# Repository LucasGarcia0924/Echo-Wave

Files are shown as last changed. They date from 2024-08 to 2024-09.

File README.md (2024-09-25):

# Echo-Wave
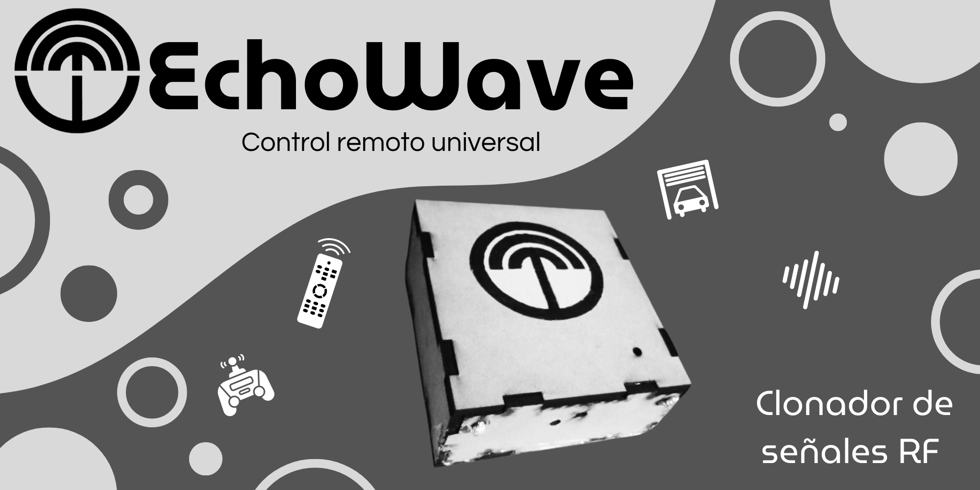
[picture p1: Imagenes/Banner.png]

Banner 

## Descripción 
Dispositivo capaz de clonar señales RF de 433mhz, siendo controlado desde una App Movil

Proyecto final asignatura de Taller de Electrónica 2024-1

Universidad Nacional de Colombia
### Integrantes
* Lucas Garcia Alvarez
* Julian Gustin Moreno
* Kevin Castellanos Peña
* Santiago Navarro

## Introducción
El proyecto EchoWave se creó con la idea de facilitar la clonación de señales RF de controles remotos de distintos tipos, utilizando materiales de bajo costo para crear un dispositivo capaz de replicar y usar dichas señales. 

## La problemática
En la actualidad, el uso de controles remotos para dispositivos que emiten señales RF, como televisores, luces y otros equipos, se ha vuelto parte de las actividades cotidianas. Sin embargo, los usuarios enfrentan varios inconvenientes:

- Limitaciones de compatibilidad: Muchas veces los usuarios necesitan múltiples controles remotos, cada uno con una función específica, lo que resulta incómodo y poco eficiente.
- Falta de flexibilidad: Las tecnologías existentes no permiten la clonación o replicación de señales de RF de manera sencilla, lo que genera frustración entre los usuarios que requieren soluciones rápidas y accesibles.
- Riesgos de seguridad: Clonar señales RF sin los adecuados controles de seguridad puede conllevar riesgos, lo que hace que los usuarios se sientan inseguros al intentar utilizar tecnologías más flexibles.
Estas problemáticas crean la necesidad de desarrollar soluciones más accesibles y económicas que permitan clonar y utilizar señales RF de manera segura y eficiente, facilitando así las acciones cotidianas de los usuarios.

El proyecto EchoWave busca solucionar esta problemática mediante la creación de un dispositivo de bajo costo, flexible y eficiente, que permita la clonación y uso de señales de RF de manera segura, mejorando la experiencia del usuario y reduciendo la cantidad de controles remotos necesarios para interactuar con múltiples dispositivos.
## La solución planteada (los módulos usados)
La solución se diseña a partir de tecnologías simples, de fácil acceso y fabricación, enfocados en parte a que sea algo accesible para todo el mundo, por lo que a partir de esto y demás requisitos descritos a continuacion, se eligen los siguientes componentes:
- Chip ESP32
- Batería Recargable IN18650
- Modulo MHCD 42
- Transceptor HC-12
- Servomotor SG90
- Zumbador
- Case en Impresion 3D y Corte Laser
## El funcionamiento del proyecto desde el punto de vista del usuario

El EchoWave funciona como un control remoto universal, que mediante una aplicación, clona señales RF, como las de un control de televisor, controles para puertas de garaje o portones, y otros dispositivos similares  
Su uso consta tan solo de descargar la aplicación, clonar señales, cargar el dispositivo mediante el cable incluido y bloquear las señales con el pulsador en la parte superior del case.

## Recomendaciones y conclusiones
### Conclusiones:
En este proyecto se logró avanzar en le creación de una herramienta capaz de simplificar las tarjetas de acceso y controles a distancia de forma compacta, sin embargo, se enfocó el proyecto a las señales de radiofrecuencia, donde por medio de un transceptor recibe estas señales. Dentro del proyecto se utilizaron componentes con presupuesto reducido, confirmando que en el mercado se consiguen dispositivos de bajo precio y con las características que permiten manejar las diferentes señales y comunicaciones que se implementan aquí. Se plantea en un futuro implementarle la opción de usarse a bluetooth y hacer el uso de este desde una app del celular, dado que, quitando al tranceptor el cual es controlado desde la app diseñada por Slavko Zdravevski se implementó un grupo de pulsadores sencillos para que inicie su funcionamiento, por lo que lo ideal sería integrar todos estos comandos dentro de la app y así eliminar los pulsadores de la PCB.

### Recomendaciones para trabajos futuros:
Visualizamos que puede ser muy útil, buscar diferentes antecedentes de proyectos similares, componentes capaces de llevar a cabo la tarea y evaluar cuál lenguaje de programación ha de usarse.
Si se quiere hacer un trabajo en grupo, debe existir muy buena comunicación, de forma continua y clara entre todos, para que no se se tengan retrasos en el proceso, facilitando la corrección de errores y permitiendo un continuo ciclo de ideas y retroalimentación, para que el proyecto fluya correctamente.
Se deben tener en cuenta los posibles obstáculos que se pueden presentar durante el proceso, como puede ser el mal funcionamiento de un componente, o el fallo del código; para ello es necesario saber que otras alternativas existen, para corregir el error que se produzca al realizar el proyecto.

## WIKI
Si desea conocer más sobre este proyecto, podrá encontrar toda la documentación en la sección de [wiki](https://github.com/LucasGarcia0924/Echo-Wave/wiki), además, en este apartado en la parte superior se encuentran adjuntos todos los archivos relacionados con el proyecto.

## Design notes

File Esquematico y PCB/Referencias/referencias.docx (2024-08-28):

ESP-32 DEVKIT 1

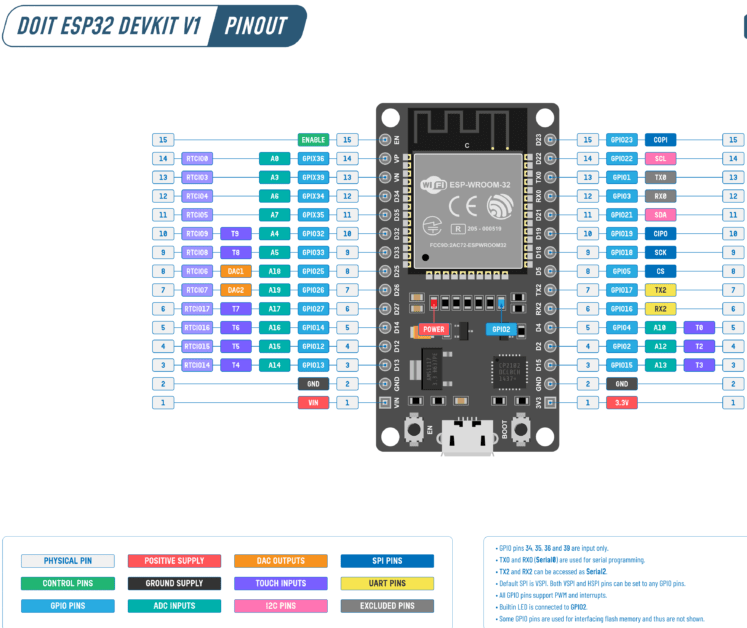
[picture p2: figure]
ESP32-DevKit-V1-Pinout-Diagram-r0.1-CIRCUITSTATE-Electronics-2

HC-12

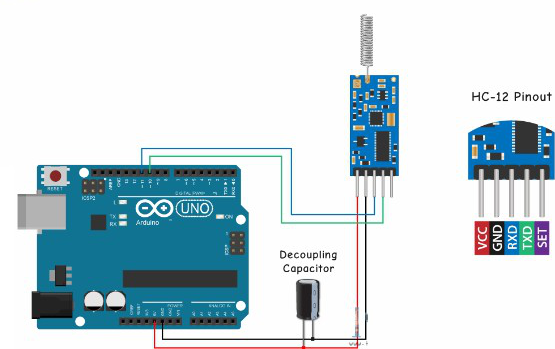
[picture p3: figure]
HC-12 SI4438/4463 wireless long range 433M serial
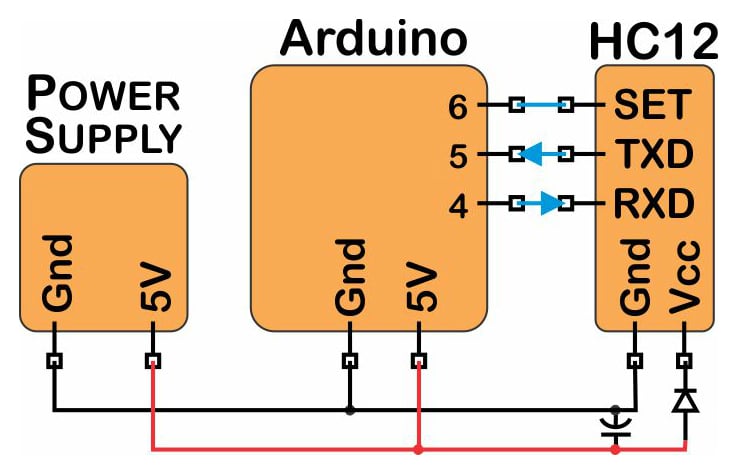
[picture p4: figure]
Understanding and Implementing the HC-12 Wireless Transceiver Module - Projects
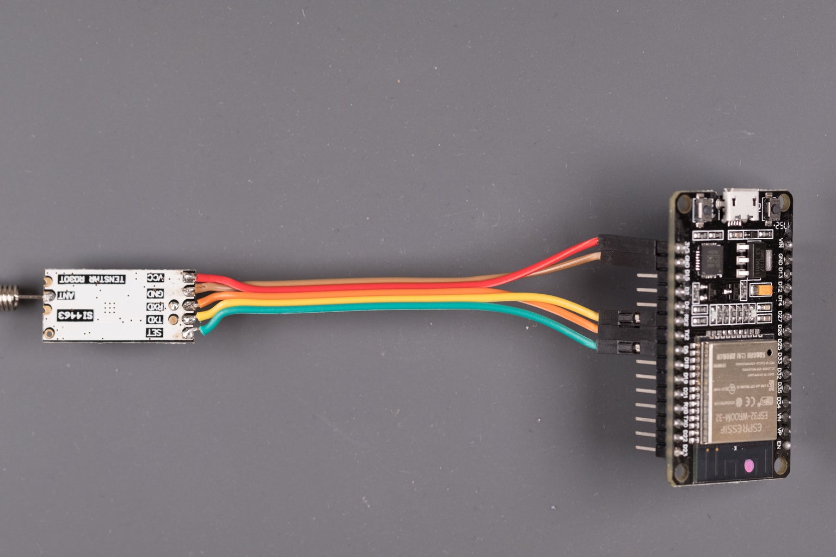
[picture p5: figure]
Easy IOT - ESP32 Based RF Sensor Hub : 13 Steps (with Pictures) - Instructables

Servomotor:

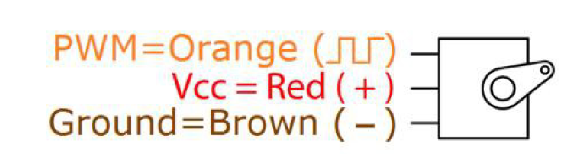
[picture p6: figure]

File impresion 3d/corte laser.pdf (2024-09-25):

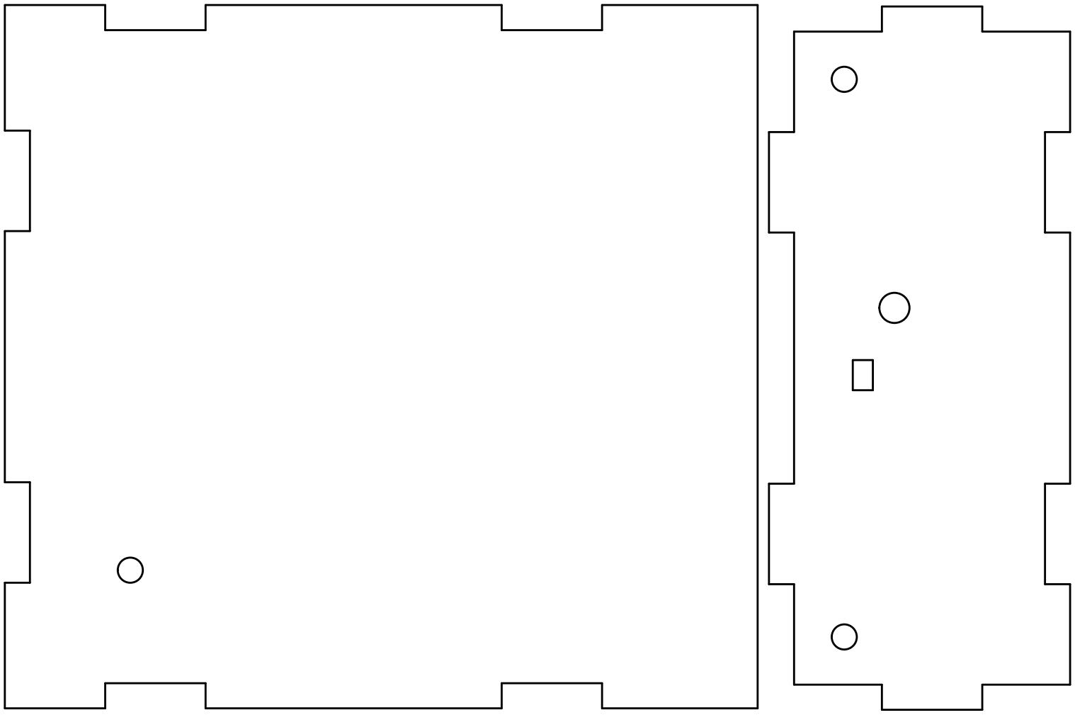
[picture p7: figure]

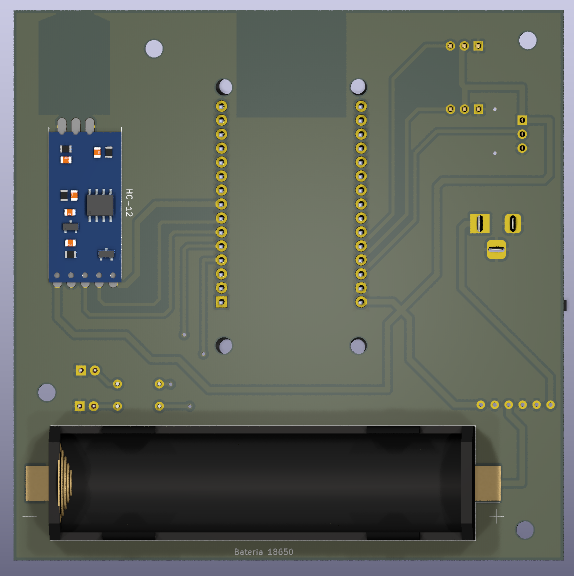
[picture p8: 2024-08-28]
Imagenes/PCB diseño virtual 2.png

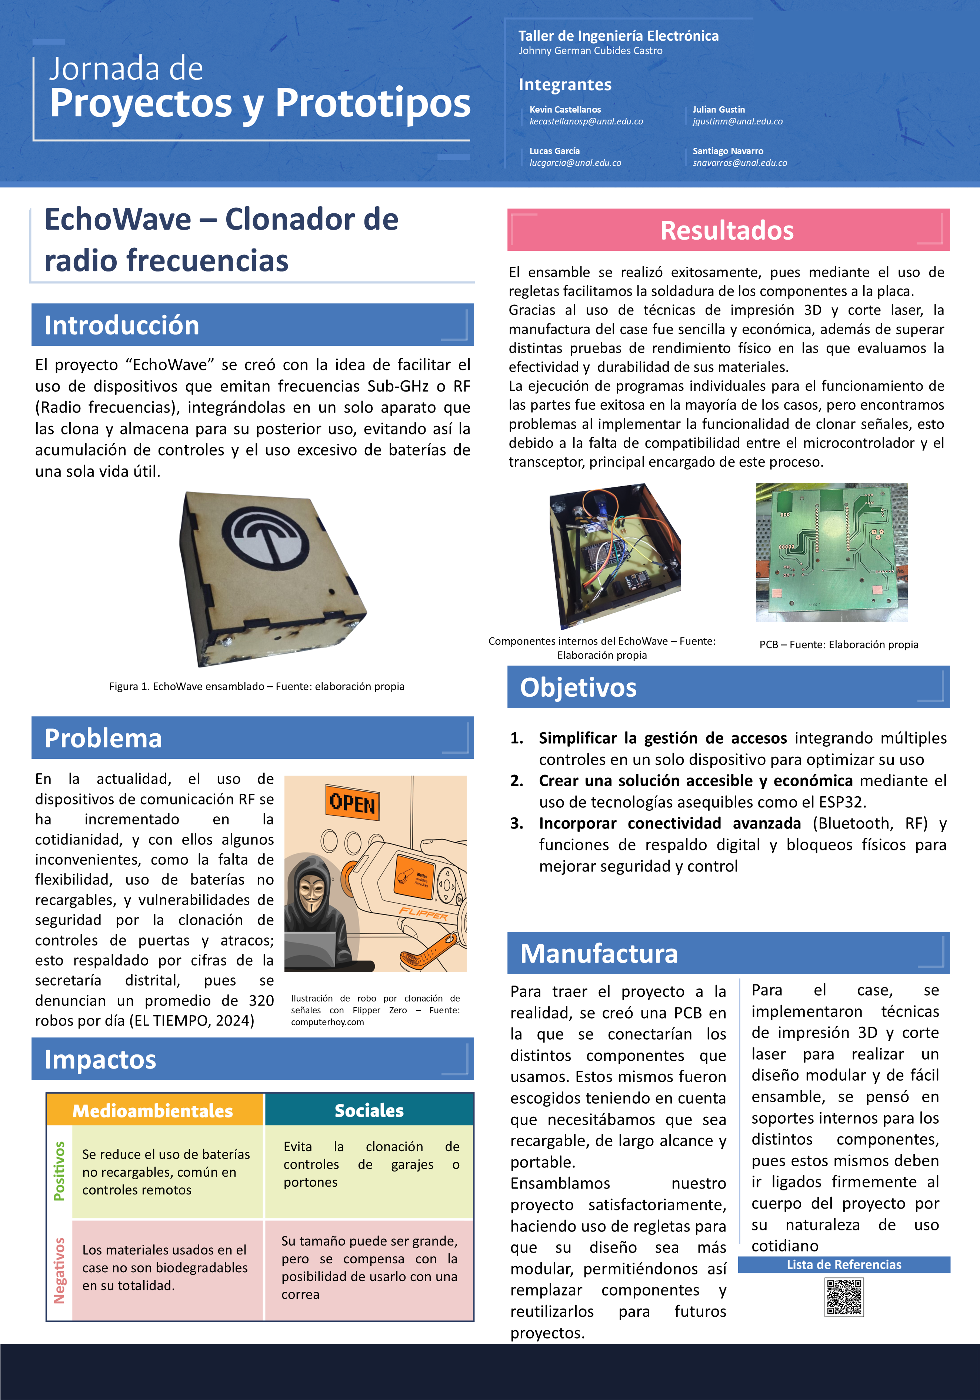
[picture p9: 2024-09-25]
Imagenes/Poster electronica.png

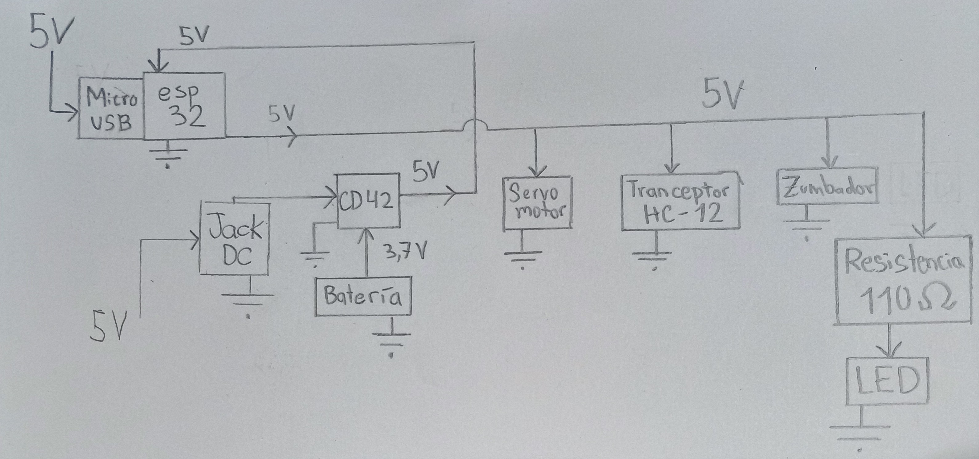
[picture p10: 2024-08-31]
Imagenes/Diseño Tecnológico.png

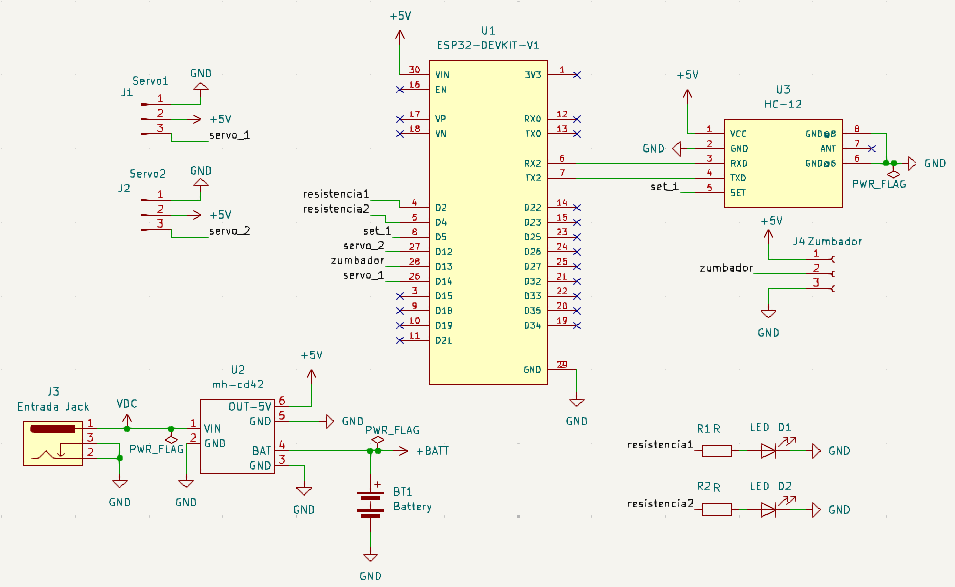
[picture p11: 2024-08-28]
Imagenes/Diseño Esquemático.png

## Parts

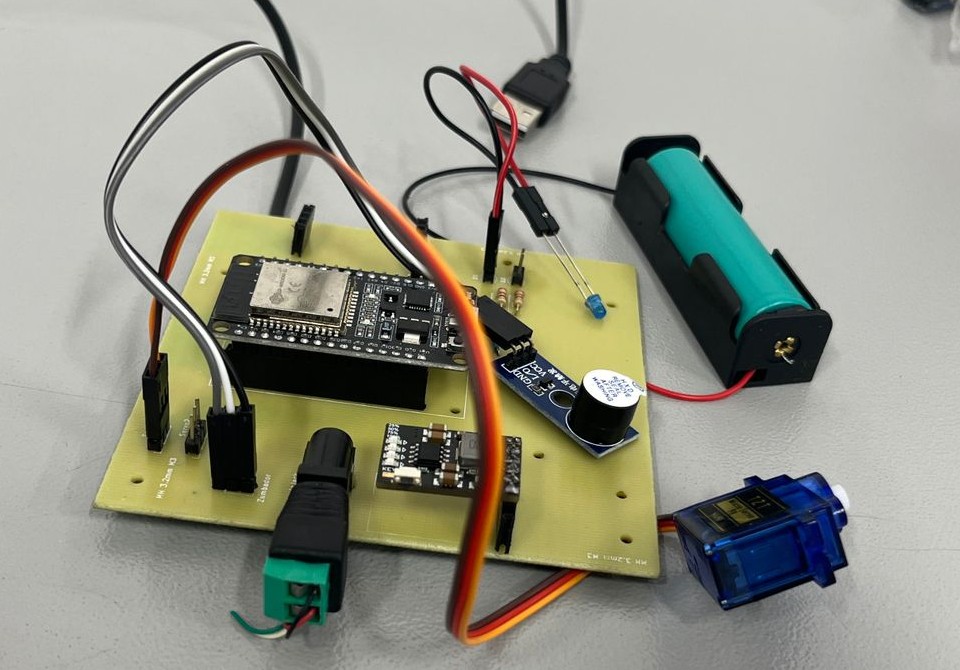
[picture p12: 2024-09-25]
Imagenes/PCB-componentes-01.jpg

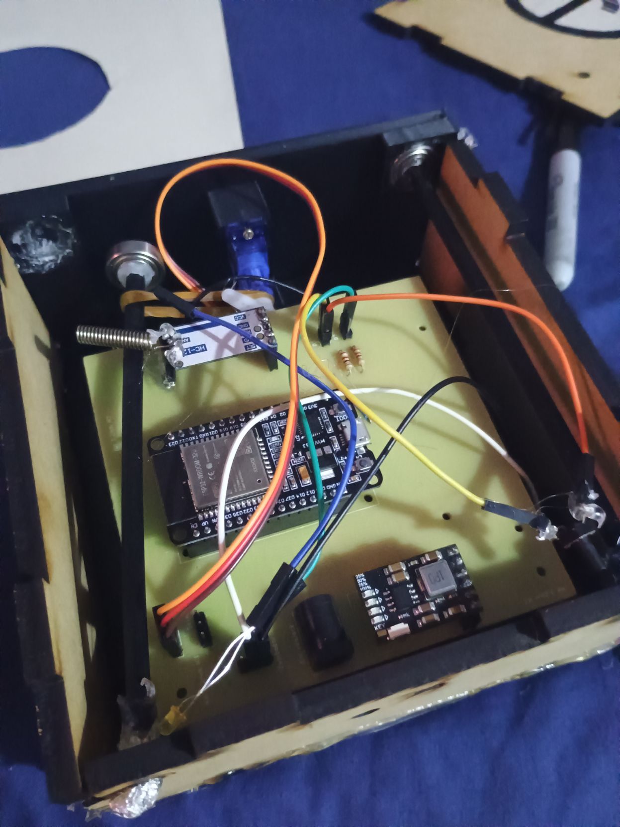
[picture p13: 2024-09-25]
Imagenes/PCB-componentes-03.jpg

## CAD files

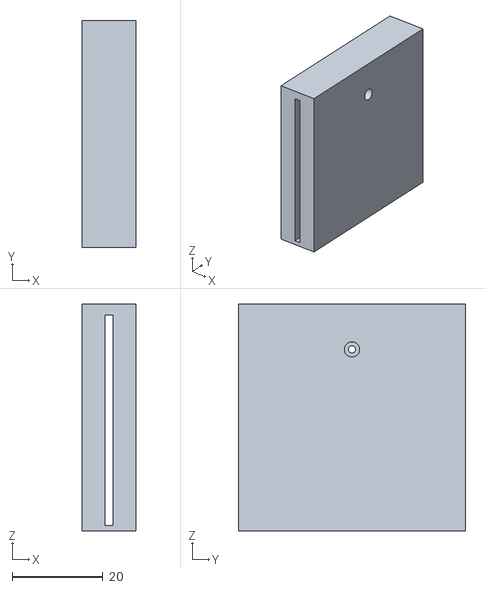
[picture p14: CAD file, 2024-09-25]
impresion 3d/cosito.stl
11.8 x 50.0 x 50.0

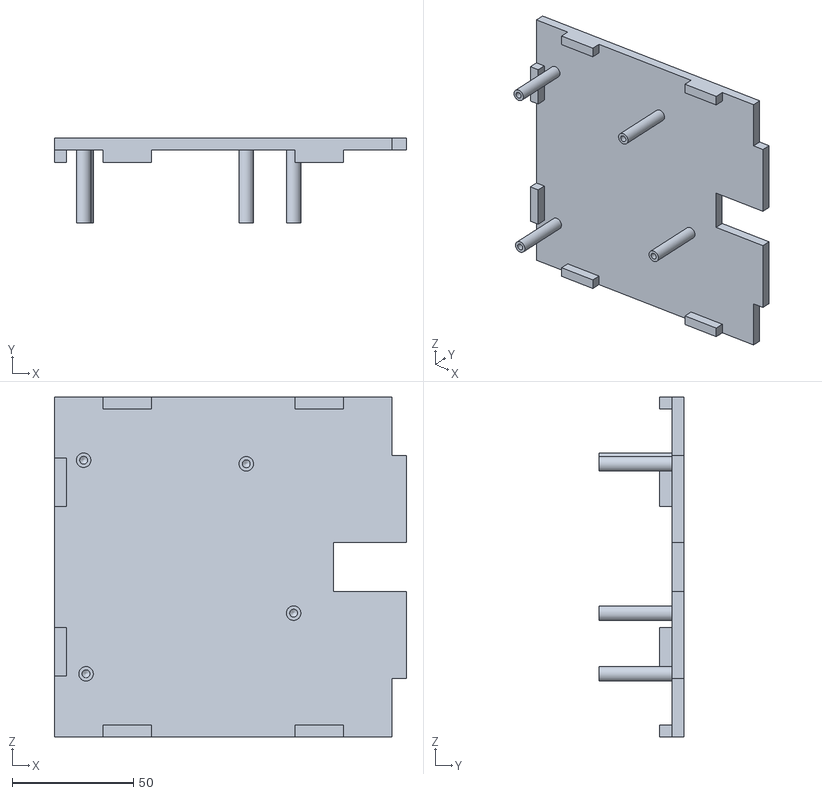
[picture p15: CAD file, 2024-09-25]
impresion 3d/5.stl
145.0 x 35.0 x 140.0

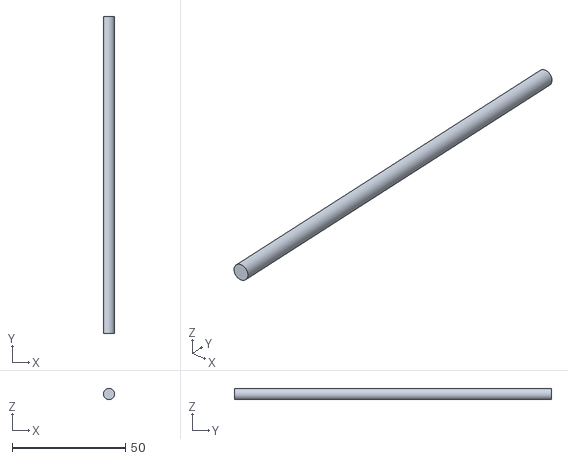
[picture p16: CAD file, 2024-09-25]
impresion 3d/eje.stl
4.99 x 140.0 x 5.00

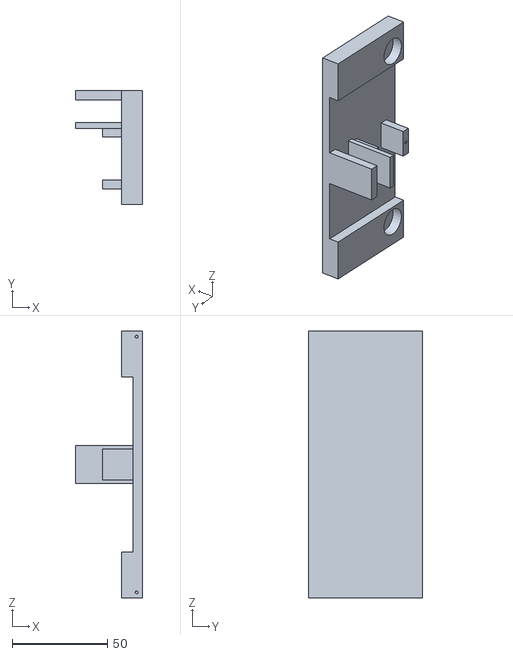
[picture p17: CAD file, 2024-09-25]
impresion 3d/1.stl
35.0 x 60.0 x 140.0

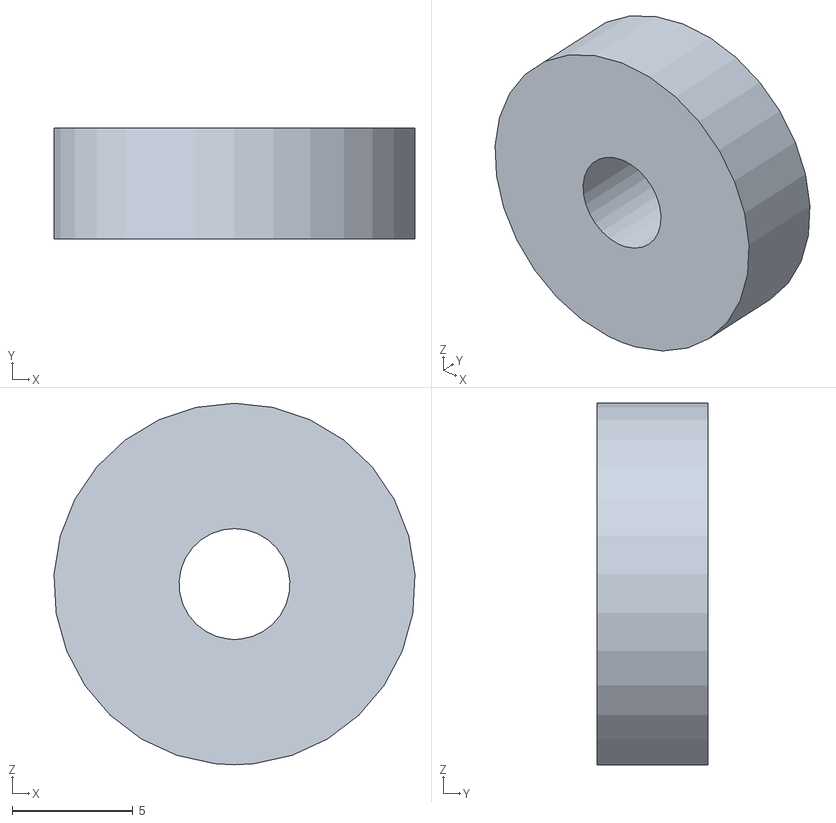
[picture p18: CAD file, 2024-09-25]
impresion 3d/bolita.stl
15.0 x 4.60 x 15.0

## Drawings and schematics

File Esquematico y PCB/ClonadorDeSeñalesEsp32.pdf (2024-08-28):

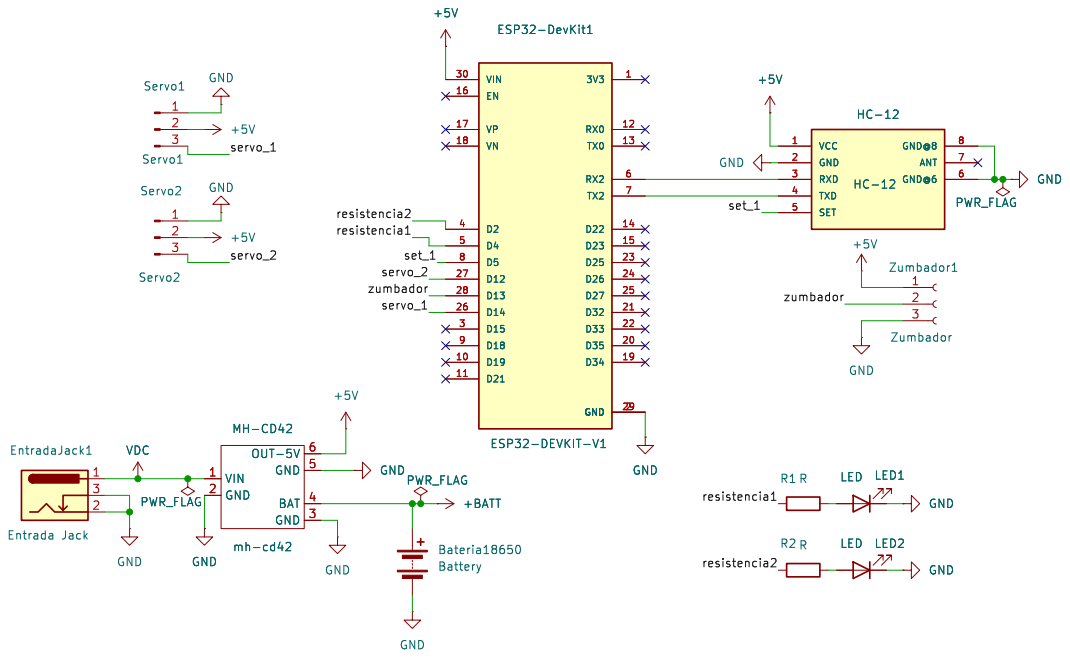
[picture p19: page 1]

Id: 1/1 Title: File: þÿClonadorDeSeñalesEsp32.kicad_sch Sheet: /

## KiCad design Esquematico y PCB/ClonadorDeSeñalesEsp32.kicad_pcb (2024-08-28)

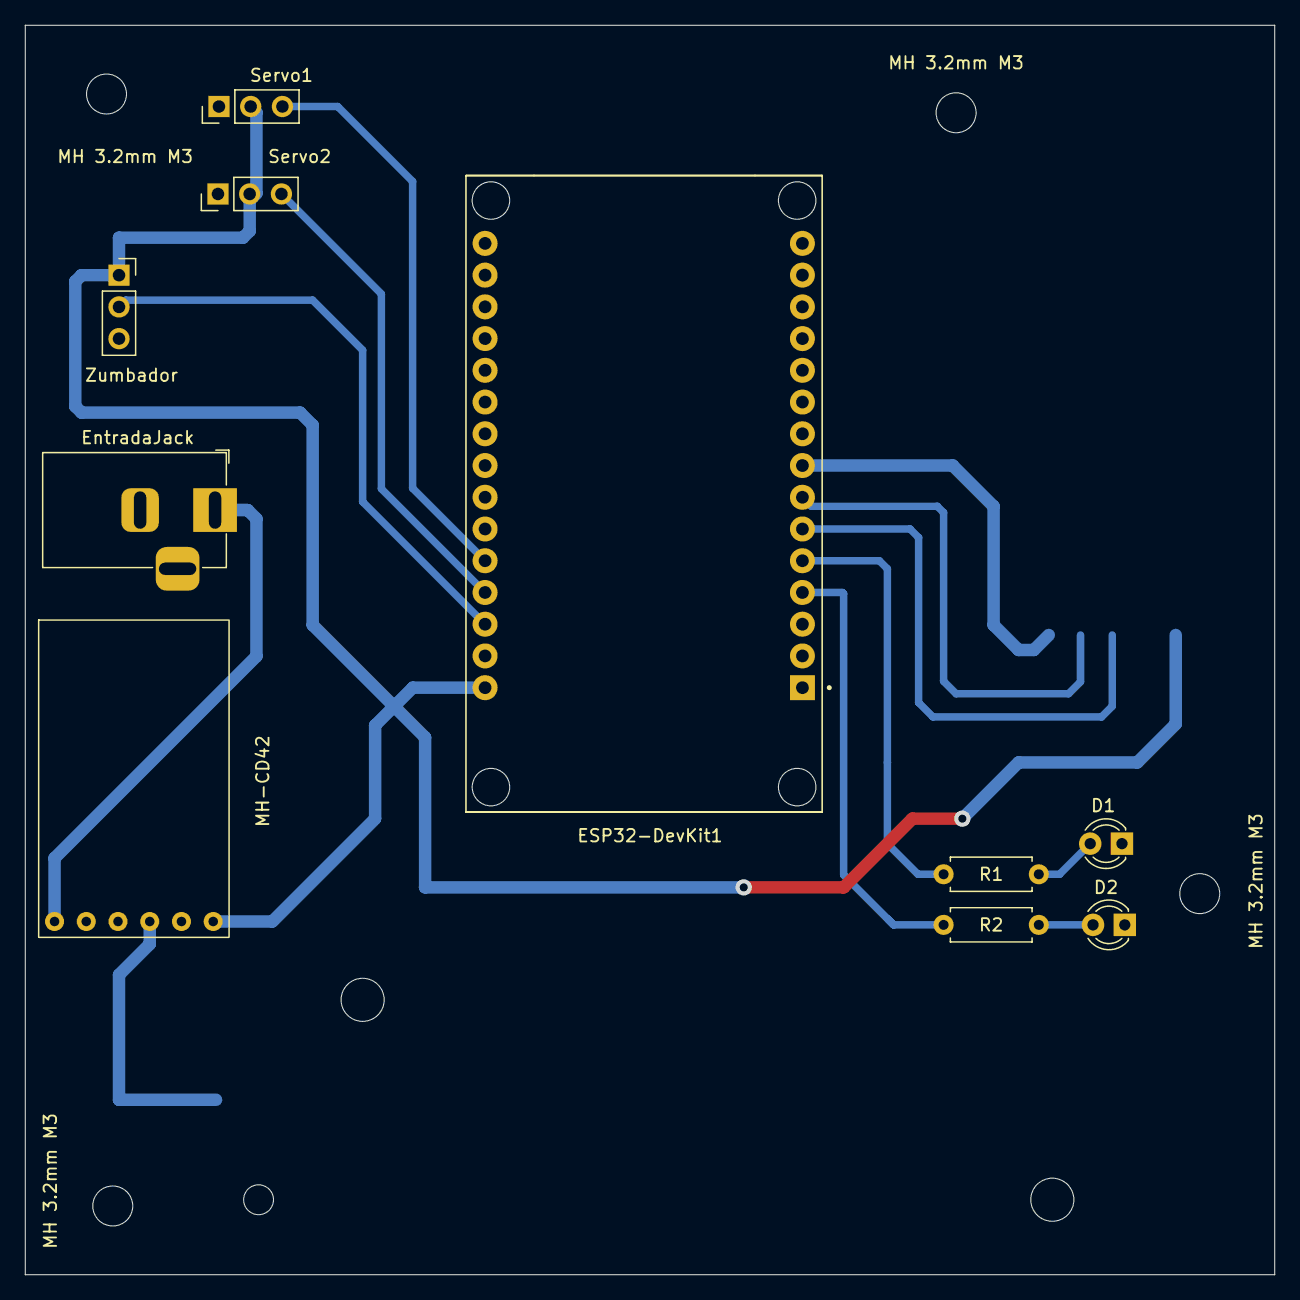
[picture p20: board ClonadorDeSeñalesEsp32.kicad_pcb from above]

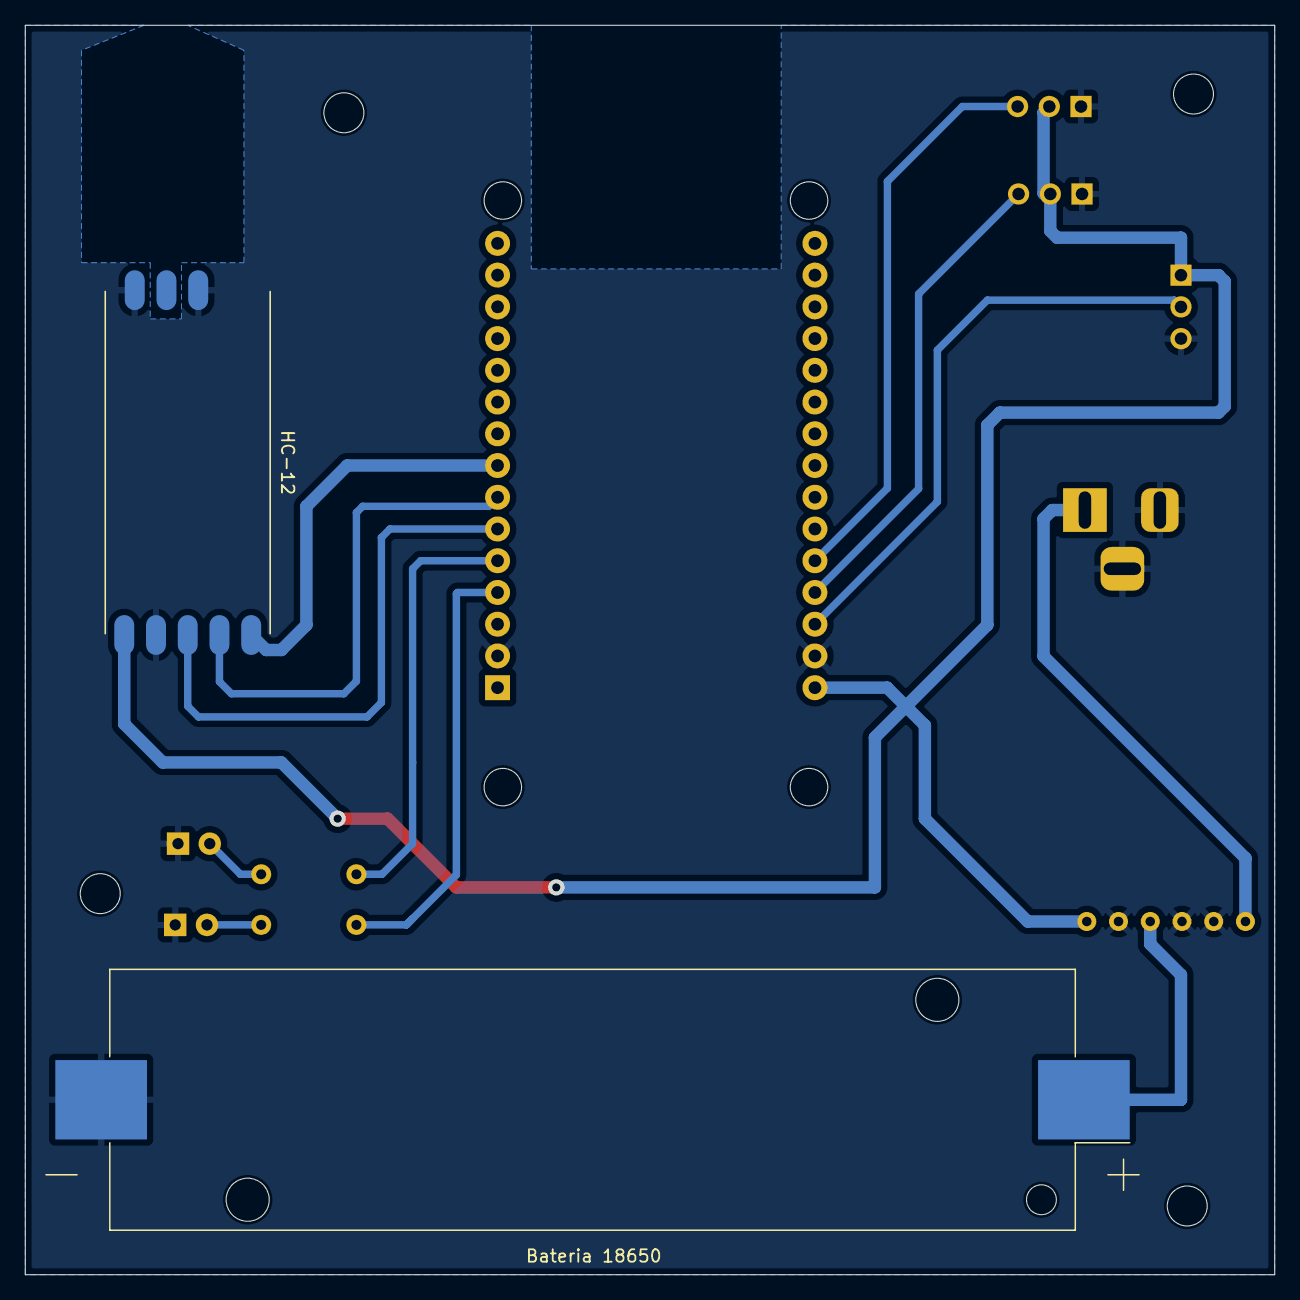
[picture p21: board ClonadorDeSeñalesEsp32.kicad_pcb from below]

Board: 2 copper layers, 100.0 x 100.0 mm, 16 parts (2 on the bottom side), 14 nets.

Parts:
Bateria 18650: Battery; BatteryHolder_Keystone_1042_1x18650
D1, D2: LED; LED_D3.0mm
ESP32-DevKit1: ESP32-DEVKIT-V1; MODULE_ESP32_DEVKIT_V1
EntradaJack: Entrada Jack; BarrelJack_Horizontal
HC-12: HC-12
MH 3.2mm M3: MH 3.2mm M3; MountingHole_3.2mm_M3
MH 3.2mm M3#2, MH 3.2mm M3#4: MH 32mm M3; MountingHole_3.2mm_M3
MH 3.2mm M3#3: MountingHole_3.2mm_M3
MH-CD42: MH-CD42; mh-cd42
R1, R2: R; R_Axial_DIN0207_L6.3mm_D2.5mm_P7.62mm_Horizontal
Servo1: Servo1; PinHeader_1x03_P2.54mm_Vertical
Servo2: Servo2; PinHeader_1x03_P2.54mm_Vertical
Zumbador: Zumbador; PinSocket_1x03_P2.54mm_Vertical

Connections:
+5V: ESP32-DevKit1.30 (VIN), HC-12.1 (VCC), MH-CD42.6 (OUT-5V), Servo1.2, Servo2.2, Zumbador.1
+BATT: Bateria 18650.1 (+), MH-CD42.4 (BAT)
/resistencia1: ESP32-DevKit1.5 (D4), R1.1
/resistencia2: ESP32-DevKit1.4 (D2), R2.1
/servo_1: ESP32-DevKit1.26 (D14), Servo1.3
/servo_2: ESP32-DevKit1.27 (D12), Servo2.3
/set_1: ESP32-DevKit1.8 (D5), HC-12.5 (SET)
/zumbador: ESP32-DevKit1.28 (D13), Zumbador.2
GND: Bateria 18650.2 (-), D1.1 (K), D2.1 (K), ESP32-DevKit1.2 (GND), ESP32-DevKit1.29 (GND), EntradaJack.2, EntradaJack.3, HC-12.2 (GND), HC-12.6 (GND@6), HC-12.8 (GND@8), MH-CD42.2 (GND), MH-CD42.3 (GND), MH-CD42.5 (GND), Servo1.1, Servo2.1, Zumbador.3
unnamed: D1.2 (A), R1.2
unnamed: D2.2 (A), R2.2
unnamed: ESP32-DevKit1.6 (RX2), HC-12.3 (RXD)
unnamed: ESP32-DevKit1.7 (TX2), HC-12.4 (TXD)
VDC: EntradaJack.1, MH-CD42.1 (VIN)

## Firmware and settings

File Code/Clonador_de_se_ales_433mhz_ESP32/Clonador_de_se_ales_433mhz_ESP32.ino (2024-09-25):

// The script is written by Slavko Zdravevski
// If you want to support my work, you can subscribe to my youtube channel: https://bit.ly/3FG9hpK
// I do a lot of interesting things in my free time, so you might find something of your interest or we can exchange ideas and knowledge

// Libraries, I also put them on github
#include "BluetoothSerial.h"
#include <RCSwitch.h>

// Pinout declaration
int ledPin = 2;
int rfReceiverPin = 16;
int rfTransmitterPin = 17; 

// Additional variables needed through the code
unsigned long currentSecounds, previousSecoundsRecord;
String receivedCommand;
String commandToSend;

unsigned long receivedCodes[100];
int receivedProtocols[100];
int receiverCounter = 0;
bool canStoreCurrentCode = true;
unsigned long previousMillisLed = 0;
bool blinkLed = false;
int ledCounter = 0;

BluetoothSerial SerialBT;
RCSwitch mySwitch = RCSwitch();

void setup() {
  Serial.begin(115200);
  SerialBT.begin("ESP32"); // If you want to use my app, leave this line as it is, otherwise, it won't work
  mySwitch.enableReceive(rfReceiverPin);
  mySwitch.enableTransmit(rfTransmitterPin);
  pinMode(ledPin, OUTPUT);
}

void loop() {
  currentSecounds = millis() / 1000;
  receiveBtData();
  decodeRfSignals();
  checkLedState();
  
  if ((currentSecounds - previousSecoundsRecord) >= 4) {
    previousSecoundsRecord = currentSecounds;
    SerialBT.println("Good connection");
  }
}

// Method declarations
void receiveBtData() { // Receives Bluetooth data sent from the Android device and acts accordingly
  if (SerialBT.available()) {
    receivedCommand += String((char)SerialBT.read());
  } else {
    receivedCommand.toLowerCase();
    if (receivedCommand != "") {
      Serial.println(receivedCommand);
      if (receivedCommand == "refresh data") {
        sendCurrentRfData();
      } else {
        int codeForSend = receivedCommand.substring(0,receivedCommand.indexOf("|")).toInt();
        int protocolForSend = receivedCommand.substring(receivedCommand.indexOf("|")+1, receivedCommand.length()).toInt();
        Serial.println(codeForSend);
        Serial.println(protocolForSend);
        sendCodeOverRfModule(codeForSend, protocolForSend);
      }
      receivedCommand = "";
    }
  }
}

void sendCurrentRfData() { // Sends the currently stored data in the microcontroller's memory to the phone over Bluetooth
  if (receiverCounter != 0) {
    for (int i=0; i<receiverCounter; i++) {
      commandToSend = String(receivedCodes[i])+"|"+String(receivedProtocols[i]);
      SerialBT.println(commandToSend);
      delay(200);
    }
  } else {
    SerialBT.println("empty memory");
  }
}

void sendCodeOverRfModule(int code, int protocol) { // Sends the code got from the parameter over the radio module
  blinkLed = true;
  // Optional set protocol (default is 1, will work for most outlets)
  mySwitch.setProtocol(protocol);
  mySwitch.send(code, 24);
}

void decodeRfSignals() { // Decodes the 433/315 signals received by the module, and stores them into local arrays
  if (mySwitch.available()) {
    blinkLed = true;
    for (int i=0; i<receiverCounter; i++) {
      if (receivedCodes[i] == mySwitch.getReceivedValue()) {
        canStoreCurrentCode = false;
        break;
      }
    }

    if (canStoreCurrentCode) {
      receivedCodes[receiverCounter] = mySwitch.getReceivedValue();
      receivedProtocols[receiverCounter] = mySwitch.getReceivedProtocol();

      Serial.println(mySwitch.getReceivedValue());
      Serial.println(receiverCounter);
      receiverCounter++;
    }

    canStoreCurrentCode = true;

    mySwitch.resetAvailable();
  }
}

void checkLedState() { // Checks whether the led should blink
  unsigned long currentMillisLed = millis();  
  if (blinkLed) {
    if ((unsigned long)(currentMillisLed - previousMillisLed) >= 100) {
      if (ledCounter == 0) {
        digitalWrite(ledPin, HIGH);
        ledCounter = 1;
      } else if (ledCounter == 1) {
        digitalWrite(ledPin, LOW);
        ledCounter = 2;
      } else if (ledCounter == 2) {
        digitalWrite(ledPin, HIGH);
        ledCounter = 3;
      } else if (ledCounter == 3) {
        digitalWrite(ledPin, LOW);
        ledCounter = 0;
        blinkLed = false;
      }
      previousMillisLed = currentMillisLed;
    }
  }
}

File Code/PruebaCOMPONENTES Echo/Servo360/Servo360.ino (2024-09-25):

#include <ESP32Servo.h>  // Incluimos la biblioteca Servo para la ESP32

Servo miServo;  // Crea un objeto servo
const int servoPin = 14;  // Pin donde está conectado el servo
const int pulsadorPin = 4;  // Pin donde está conectado el pulsador

bool estadoPasadoPulsador = HIGH;  // Estado anterior del botón
bool servoEnMovimiento = false;  // Estado del servo

void setup() {
  miServo.attach(servoPin);  // Conectamos el servo al pin
  miServo.write(90);          // Detiene el servo al inicio
  pinMode(pulsadorPin, INPUT_PULLUP); // Configura el pin del botón como entrada con pull-up
}

void loop() {
  // Lee el estado actual del botón
  bool estadoActualPulsador = digitalRead(pulsadorPin);

  // Detecta el flanco de bajada (cuando se presiona el botón)
  if (estadoPasadoPulsador == HIGH && estadoActualPulsador == LOW) {
    if (!servoEnMovimiento) {
      // Mueve el servo hacia adelante
      miServo.write(180);  // Velocidad máxima hacia adelante
      delay(1000);         // Mantiene el movimiento por 1 segundo
      miServo.write(90);   // Detiene el servo
      servoEnMovimiento = true; // Cambia el estado
    } else {
      // Regresa el servo a la posición original
      miServo.write(0);    // Velocidad máxima hacia atrás
      delay(1000);         // Mantiene el movimiento por 1 segundo
      miServo.write(90);   // Detiene el servo
      servoEnMovimiento = false; // Cambia el estado
    }
  }

  estadoPasadoPulsador = estadoActualPulsador; // Actualiza el estado anterior del botón
}

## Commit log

2024-08-28 Guardado de PCB en la Nube
    [ClonadorDeSeñalesEsp32-2.kicad_sch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]
2024-08-28 Cambio de nombre
2024-08-28 Delete PCB/ClonadorDeSeñalesEsp32/GERBER.rar
    Se borra el Gerber desactualizado
2024-08-28 Fin de la PCB
    [ClonadorDeSeñalesEsp32.kicad_pcb]
2024-08-28 Actualización de fotos
2024-08-28 Fin de la PCB
    PCB después de revisión del profesor
    [ClonadorDeSeñalesEsp32-B_Cu.gbr, ClonadorDeSeñalesEsp32-B_Mask.gbr, ClonadorDeSeñalesEsp32-B_Paste.gbr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]
2024-08-28 gerber final
2024-09-25 organizar carpetas
    [ClonadorDeSeñalesEsp32-2.kicad_sch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]
